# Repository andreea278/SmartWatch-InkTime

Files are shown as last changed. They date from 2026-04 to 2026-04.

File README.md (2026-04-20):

# SmartWatch InkTime 

Proiect de dezvoltare a unui ceas inteligent bazat pe microcontrolerul Nordic nRF52840, echipat cu un afișaj E-Ink și senzori pentru monitorizarea activității.

---

## Diagramă Bloc

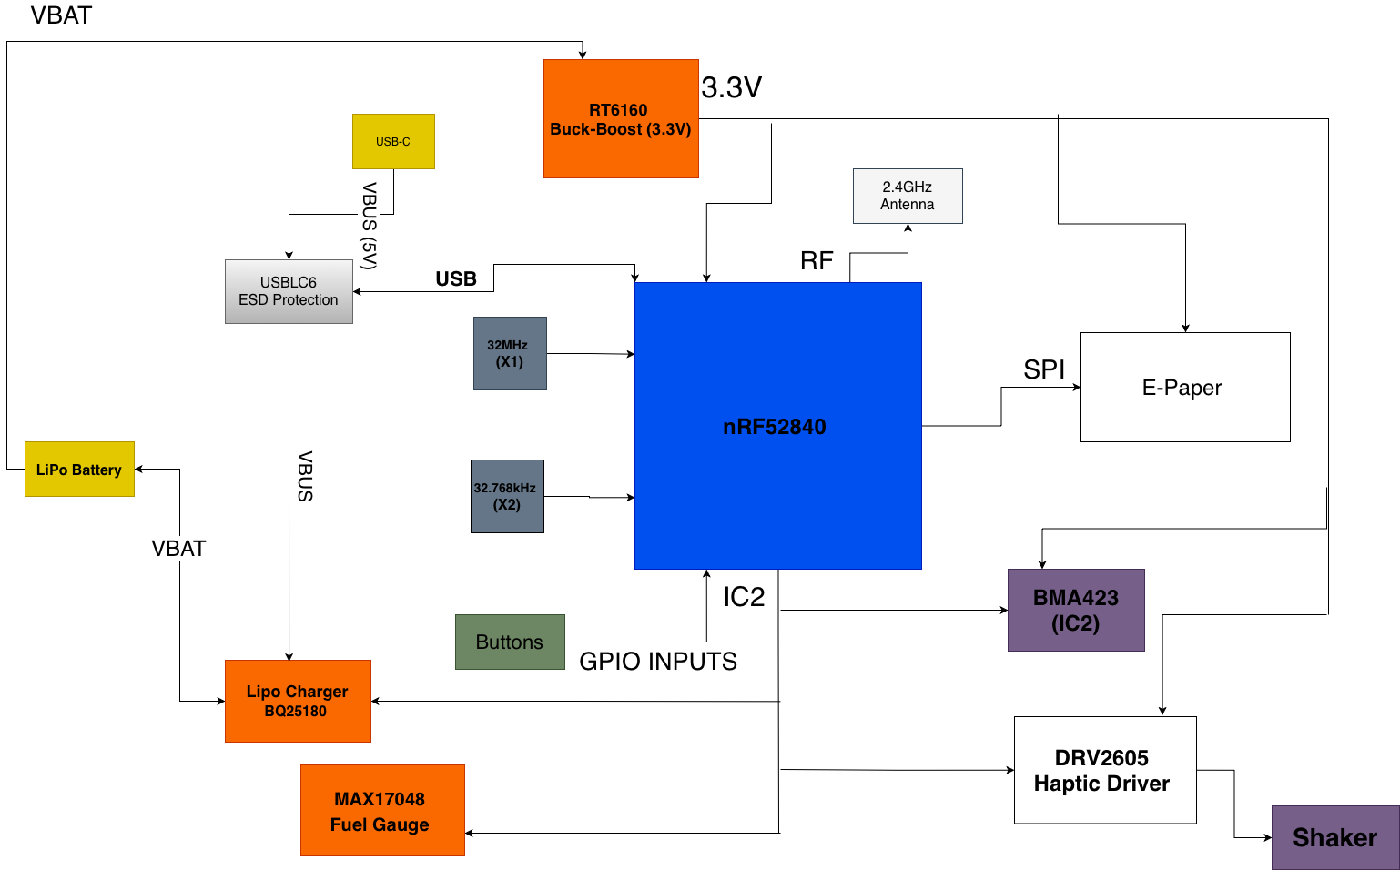
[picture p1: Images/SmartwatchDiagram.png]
Block Diagram


---
Acest proiect reprezintă o platformă open-hardware de tip smartwatch, proiectată pentru flexibilitate maximă și eficiență energetică ridicată. Construit în jurul microcontrolerului nRF52840 , dispozitivul oferă control total la nivel de regiștri pentru proiecte embedded avansate.

- **[nRF52840](https://www.nordicsemi.com/Products/nRF52840)(Microcontroler):** System on Chip bazat pe ARM Cortex-M4F tactat la 64 MHz. Include suport nativ pentru Bluetooth 5 / BLE și radio 2.4 GHz. Dispune de 1 MB Flash și 256 KB RAM și oferă interfețe versatile: SPI, I2C, UART și GPIO pentru comunicarea cu celelalte module.
- **[E-Paper 1.54"](https://www.waveshare.com/wiki/1.54inch_e-Paper_Module):** Ecran cu consum redus de energie, rezoluție 200x200 pixeli, comunică cu MCU-ul prin interfața SPI.
- **[BQ25180](https://www.ti.com/product/BQ25180)(Încărcător LiPo):** IC pentru încărcarea bateriei Li-Ion/Li-Po, controlat prin I2C. Gestionează alimentarea de 5V de la portul USB și oferă funcții de *power path management*.
- **[MAX17048](https://www.analog.com/en/products/max17048.html)(Fuel Gauge):** Cip pentru monitorizarea precisă a nivelului bateriei (State-of-Charge).
- **[RT6160](https://www.richtek.com/Products/Switching%20Regulators/Buck-Boost%20Converter/RT6160)(Regulator Buck-Boost):** Reglează tensiunea bateriei pentru a furniza o ieșire stabilă de 3.3V necesară componentelor sistemului.
- **Baterie LiPo (250 mAh):** Sursa principală de energie a dispozitivului.
- **[USBLC6-2](https://www.st.com/en/protections-and-safety/usblc6-2.html) (Protecție USB):** Protecție ESD (Electrostatic Discharge) pentru portul USB-C, prevenind deteriorarea componentelor interne.
- **[BMA423](https://www.bosch-sensortec.com/products/motion-sensors/accelerometers/bma423/):** Senzor MEMS pe 3 axe, ultra-low-power, optimizat pentru wearables, oferind funcții integrate precum numărarea pașilor, recunoașterea activității și detectarea mișcării prin întreruperi.
- **[DRV2605L](https://www.ti.com/product/DRV2605L) (Driver Haptic):** Driver controlat prin I2C pentru motorul de vibrații.
- [FIT0774](https://www.dfrobot.com/product-2264.html): Shaker
-  **[TC2030-IDC](https://www.tag-connect.com/product/tc2030-idc/)**: Conector programare SWD.
- **Cristale de tact:**
  - **[32 MHz (X1)](https://www.digikey.ro/en/products/detail/abracon-llc/ABM8G-32.000MHZ-18-D2Y-T/2269926):** Asigură frecvența principală de operare pentru MCU.
  - **[32.768 kHz (X2)](https://www.digikey.ro/en/products/detail/epson/FC-135-32.7680KA-A3/4522301):** Folosit pentru ceasul de timp real (RTC) și menținerea acurateței temporale.

## Bill of Materials (BOM)

Aceasta este lista principală de componente pentru proiectul smartwatch-ului bazat pe nRF52840.

| Component | Descriere | Cantitate | Producător | Cod Piesă | Datasheet |
| :--- | :--- | :---: | :--- | :--- | :---: |
| **nRF52840** | BLE Microcontroller | 1 | Nordic Semiconductor | nRF52840 | [Link](https://files.seeedstudio.com/wiki/XIAO-BLE/Nano_BLE_MCU-nRF52840_PS_v1.1.pdf) |
| **BMA423** | Accelerometru 3-axe (IMU) | 1 | Bosch | BMA423 | [Link](https://watchy.sqfmi.com/assets/files/BST-BMA423-DS000-1509600-950150f51058597a6234dd3eaafbb1f0.pdf) |
| **BQ25180** | Încărcător baterie / PMIC | 1 | Texas Instruments | BQ25180 | [Link](https://www.ti.com/product/BQ25180) |
| **DRV2605L** | Driver haptic | 1 | Texas Instruments | DRV2605L | [Link](https://www.ti.com/product/BQ25180) |
| **MAX17048** | Fuel gauge | 1 | Analog Devices | MAX17048G+T10 | [Link](https://www.analog.com/en/products/max17048.html) |
| **RT6160** | Buck-boost converter | 1 | Richtek | RT6160AWSC | [Link](https://www.mouser.com/datasheet/2/1458/DS6160A_02-3104604.pdf) |
| **2450AT18B100E** | Antenă chip 2.4GHz | 1 | Johanson Technology | 2450AT18B100E | [Link](https://jlcpcb.com/api/file/downloadByFileSystemAccessId/8588940948130156544) |
| **TC2030-IDC** | Conector programare | 1 | Tag-Connect | TC2030-IDC | [Link](https://www.lcsc.com/datasheet/C5444772.pdf) |
| **USB-C Connector** | Interfață alimentare/date | 1 | Kinghelm | KH-TYPE-C-16P | [Link](https://jlcpcb.com/api/file/downloadByFileSystemAccessId/8588905154556923904) |
| **FPC Connector** | Conector display e-paper | 1 | Molex | 503480-2400 | [Link](https://www.molex.com/content/dam/molex/molexdotcom/products/automated/enus/salesdrawingpdf/503/503480/5034802400_sd.pdf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) |
| **Push Buttons** | Switch-uri tactile | 3 | Panasonic | EVP-AKE31A | [Link](https://wmsc.lcsc.com/wmsc/upload/file/pdf/v2/lcsc/2301111010_PANASONIC-EVPAKE31A_C569760.pdf) |
| **MOSFETs** | Comutare putere | 2 | Vishay / Diodes Inc. | SI1308EDL / DMG2305UX | [Link](https://www.lcsc.com/datasheet/C469327.pdf) |
| **Diodes** | Diode Schottky | 3 | ON Semiconductor | MBR0530 | [Link](https://www.lcsc.com/datasheet/C77336.pdf) |
| **ESD Protection** | Protecție USB | 1 | STMicroelectronics | USBLC6-2SC6 | [Link](https://www.lcsc.com/datasheet/C7519.pdf) |
| **Crystal** | 32MHz | 1 | NDK | NX2016SA-32MHZ-EXS00A-CS11336 | [Link](https://wmsc.lcsc.com/wmsc/upload/file/pdf/v2/lcsc/2312080231_NDK-NX2016SA-32MHZ-EXS00A-CS11336_C6134317.pdf) |
| **Crystals** | 32.768kHz | 1 | Seiko Epson | FC-135 32.7680KA-A3 | [Link](https://jlcpcb.com/partdetail/SeikoEpson-FC_135_32_7680KAA3/C2650472) |

---

##  Arhitectură și Specificații Hardware

### 1. Unitatea de Procesare (CPU)
* **Microcontroler:** **nRF52840 (Nordic Semiconductor)**
    * **Arhitectură:** ARM Cortex-M4F (cu FPU), tactat la 64 MHz.
    * **Capabilități:** Suport nativ Bluetooth 5.4 (BLE), radio 2.4 GHz.
    * **Memorie:** 1 MB Flash, 256 KB RAM.
    * **Rol:** Procesare centrală, gestionarea stivei Bluetooth și coordonarea perifericelor.

### 2. Sistemul de Management al Energiei (PMU)
Sistemul utilizează un lanț de alimentare eficient pentru a prelungi durata de viață a bateriei:

* **Încărcare (PMIC):** **BQ25180**
    * Gestionează alimentarea de 5V (USB-C) și oferă protecție integrată.
* **Reglare Tensiune:** **RT6160 (Buck-Boost)**
    * Converteste tensiunea bateriei (3.0V - 4.2V) la o linie stabilă de **3.3V** cu o eficiență de peste 90%.
* **Monitorizare:** **MAX17048 (Fuel Gauge)**
    * Algoritm *ModelGauge* pentru estimarea precisă a nivelului bateriei.
 
 ### 3. Matricea de Comunicare
Sistemul utilizează magistrale digitale pentru a minimiza numărul de pini ocupați:

| Protocol | Componente Conectate | Funcție |
| :--- | :--- | :--- |
| **SPI** | E-Paper Display | Transfer rapid de pixeli pentru refresh. |
| **I2C** | BMA423, BQ25180, DRV2605L, MAX17048 | Magistrală partajată pentru senzori și PMU. |
| **GPIO** | Butoane fizice, Interrupts (BMA423) | Input utilizator și wake-up trigger. |
| **SWD** | Conector TC2030-IDC | Interfață de programare și debugging. |

### 4. Periferice 
* **Afișaj:** E-Paper 1.54" (200x200).
    * *Avantaj:* Consum de energie zero pentru menținerea imaginii (bistabil).
* **Senzor:** **BMA423 (Accelerometru)**.
    * *Rol:* Detecția pașilor, recunoașterea activității și trezirea MCU-ului din `Deep Sleep`.
* **Feedback Haptic:** **DRV2605L** + Motor vibrații.
    * *Rol:* Driver haptic inteligent pentru feedback tactil avansat (click-uri, alerte), controlat via I2C.

---

## 4. Mapare Pini nRF52840

| Pin nRF52840 | Semnal | Componentă | Interfață |
| :--- | :--- | :--- | :--- |
| **P0.00** | XL1 | Cristal X2 (32.768kHz) | XTAL |
| **P0.01** | XL2 | Cristal X2 (32.768kHz) | XTAL |
| **P0.02** | SCK | E-Paper (J1 FPC) | SPI SCK |
| **P0.03** | MOSI | E-Paper (J1 FPC) | SPI MOSI |
| **P0.05** | EPD_CS | E-Paper (J1 FPC) | SPI CS |
| **P0.06** | SDA | BMA423, BQ25180, MAX17048, DRV2605 | I2C SDA |
| **P0.07** | SCL | BMA423, BQ25180, MAX17048, DRV2605 | I2C SCL |
| **P0.08** | IMU_INT1 | BMA423 | GPIO Input |
| **P1.08** | IMU_INT2 | BMA423 | GPIO Input |
| **P0.10** | ALERT | MAX17048 | GPIO Input |
| **P0.11** | PMIC_INT | BQ25180 | GPIO Input |
| **P0.12** | HAPTIC_EN | DRV2605 | GPIO Output |
| **P0.13** | SW_UP | Buton Up | GPIO Input |
| **P0.14** | SW_ENT | Buton Enter | GPIO Input |
| **P0.15** | EPD_DC | E-Paper (J1 FPC) | GPIO |
| **P0.16** | EPD_RST | E-Paper (J1 FPC) | GPIO |
| **P0.17** | EPD_BUSY | E-Paper (J1 FPC) | GPIO Input |
| **P0.18** | RESET | TC2030-IDC | SWD / Reset |
| **P1.02** | SW_DN | Buton Down | GPIO Input |
| **SWDCLK** | SWDCLK | TC2030-IDC | SWD |
| **SWDIO** | SWDIO | TC2030-IDC | SWD |
| **ANT** | RF | Antenă 2450AT18B100E | RF |

---
## 5. Specificații Design PCB

### Reguli de Proiectare 
* **Strat 1 (Top):** Componente și rutare semnal.
* **Strat 2 (Internal):** Plan Putere (VCC/3V3).
* **Strat 3 (Internal):** Plan Masă (GND).
* **Strat 4 (Bottom):** Rutare semnal și componente.

### Constrângeri DRC
* **Trasee Putere:** 0.3 mm (îngustate sub BGA).
* **Trasee Date:** 0.15 mm (min).
* **Unghiuri:** Doar 45° sau rotunjite.
* **Antenă:** Zonă "Keep-out" (fără cupru) pe toate straturile sub antenă.
* **Decuplare:** Condensatoarele de 100nF plasate direct pe pinii de alimentare.

### Erori DRC Acceptate
* **Copper Clearance (Aprobat):** În zona fan-out-ului pentru nRF52840, clearance-ul a fost redus manual sub 0.15mm pentru a permite rutarea corectă a pinilor AQFN cu pitch mic.

---

### Design PCB
| **Top Layer** | **Bottom Layer** | **Silkscreen** |
| :---: | :---: | :---: |
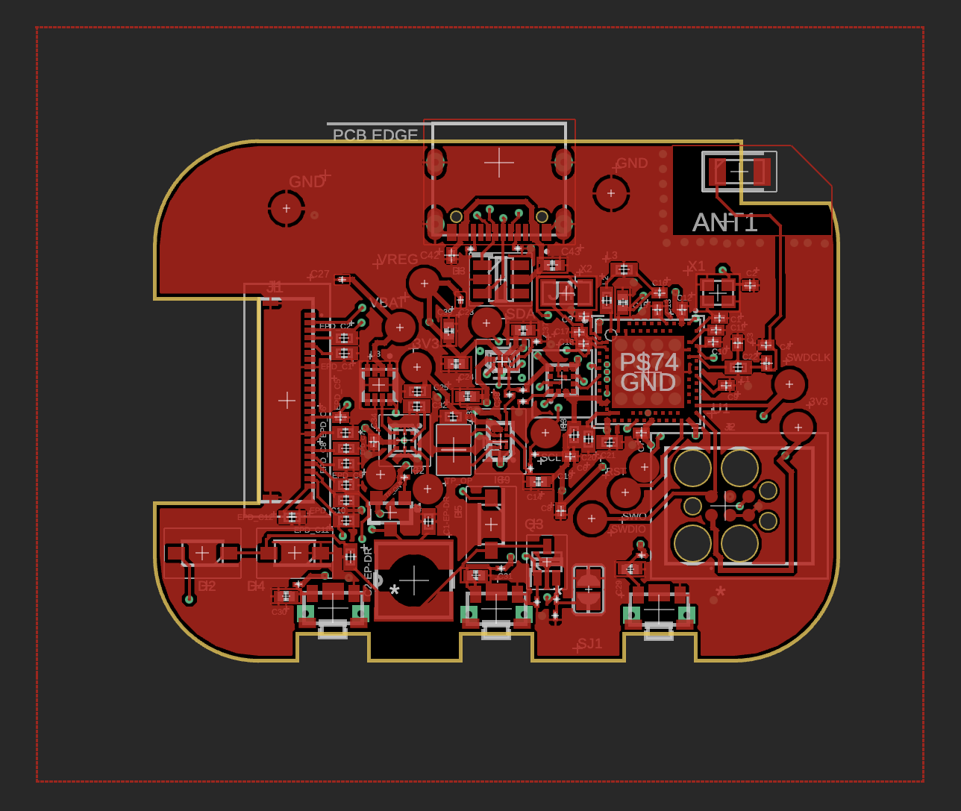
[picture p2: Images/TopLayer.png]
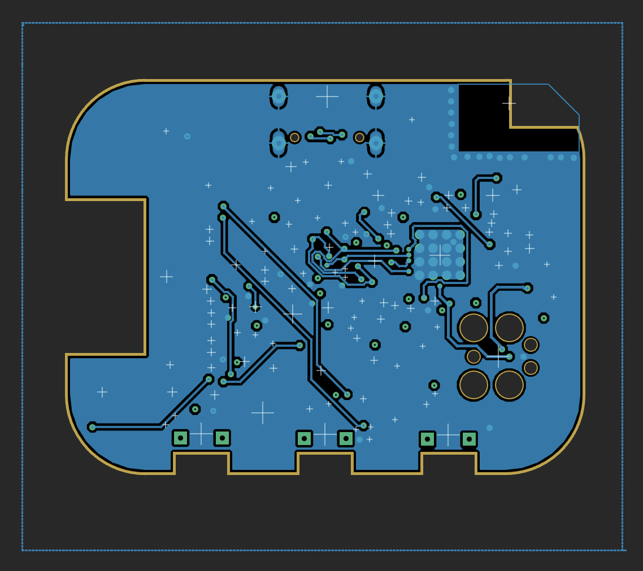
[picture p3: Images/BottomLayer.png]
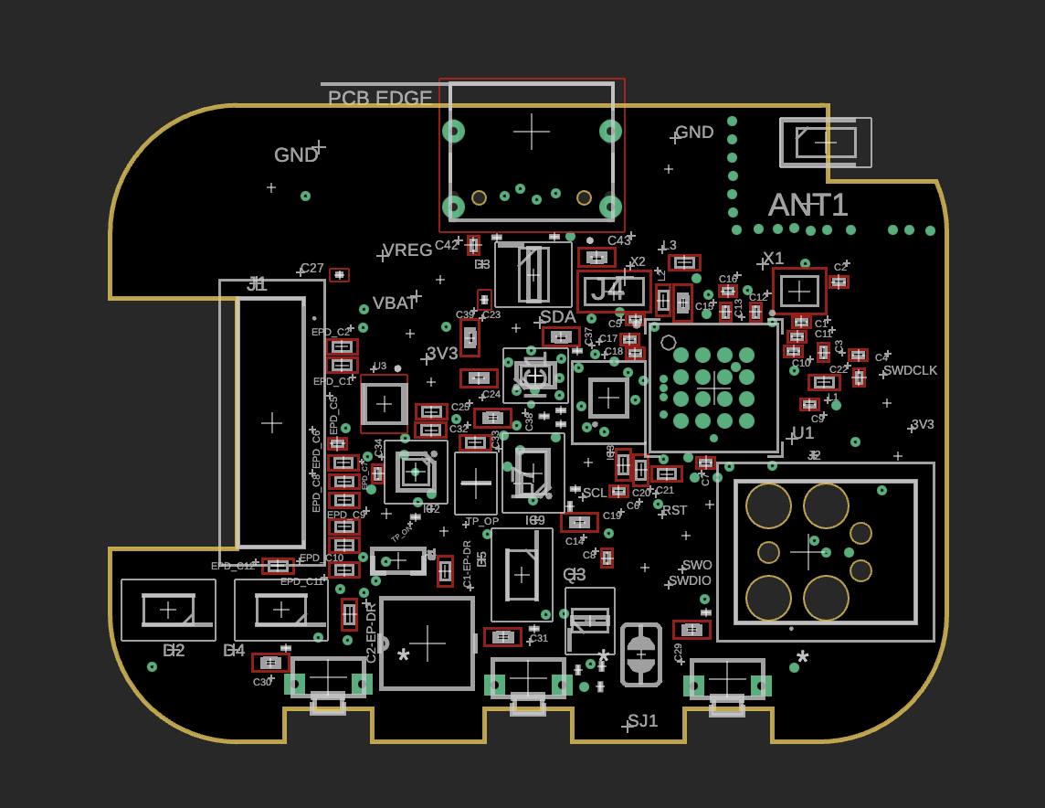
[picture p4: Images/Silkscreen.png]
|  |  |  |
| **Inner Layer 2 (GND)** | **Inner Layer 3 (Power - C63)** |
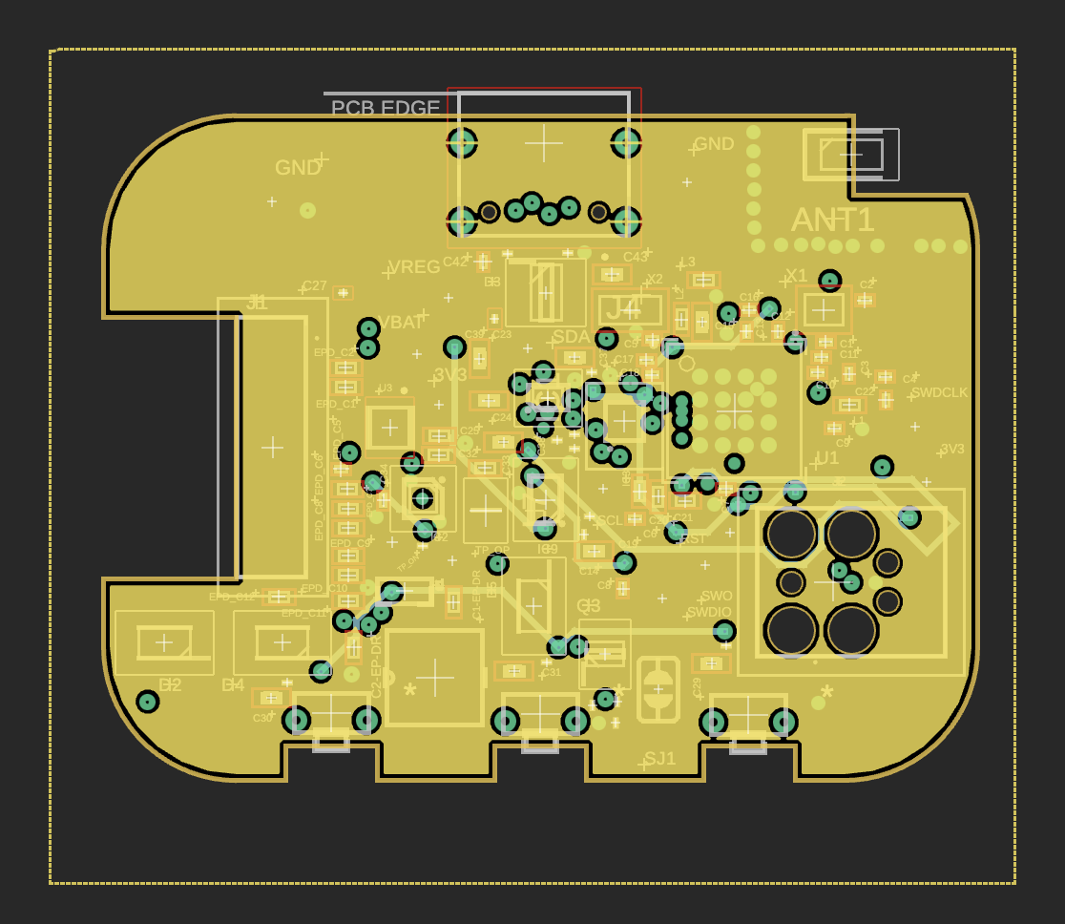
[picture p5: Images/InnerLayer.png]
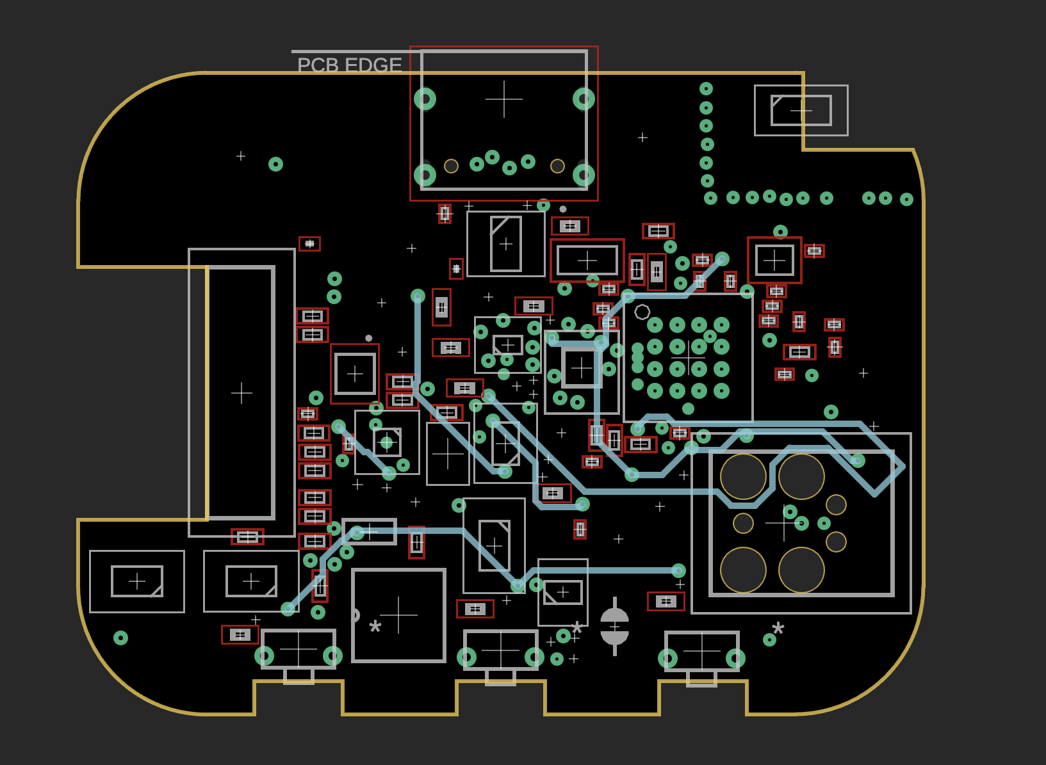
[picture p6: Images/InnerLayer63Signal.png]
|  |  |

### Design Schematic
---

| Pagina 1 - MCU & Power | Pagina 2 - Display & Senzori |
|:---:|:---:|
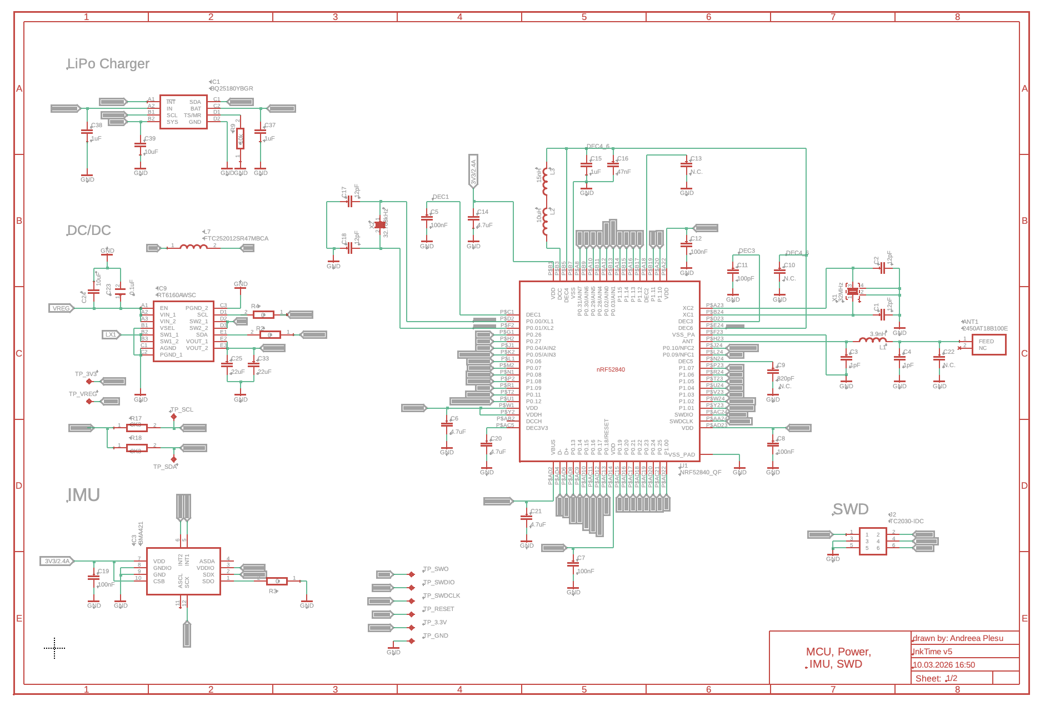
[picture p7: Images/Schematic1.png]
Schematic 1
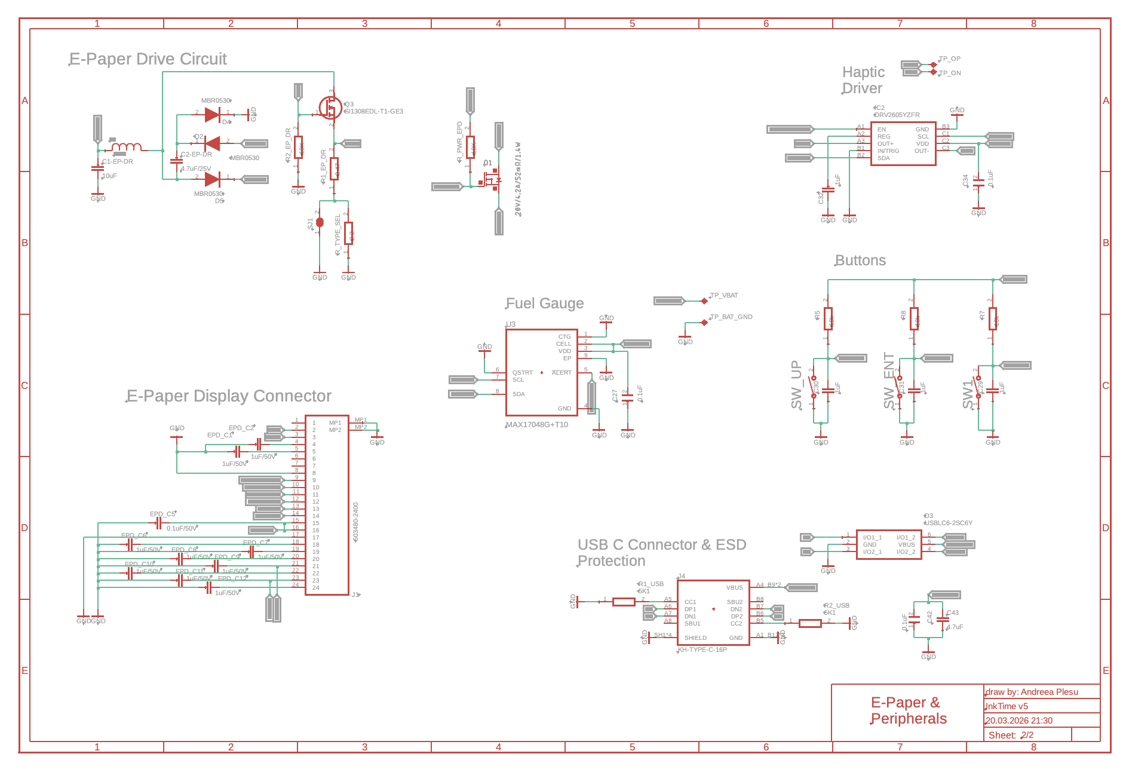
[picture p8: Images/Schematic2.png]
Schematic 2
|  width="300" |  width="300" |

---

### 3D PCB & Carcasa
| **Top View** | 
| :---: | 
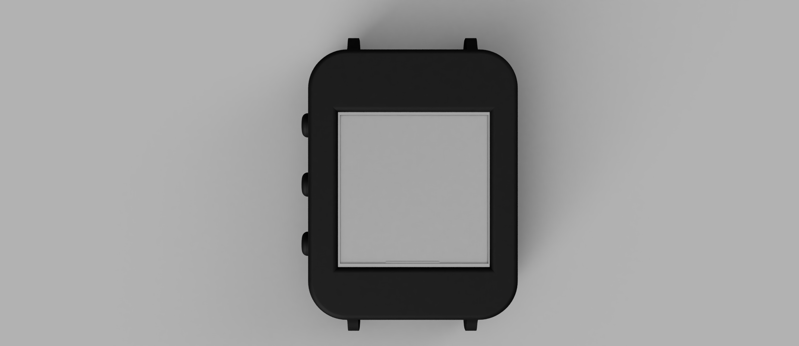
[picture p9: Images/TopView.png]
|  | 
**Side View** |
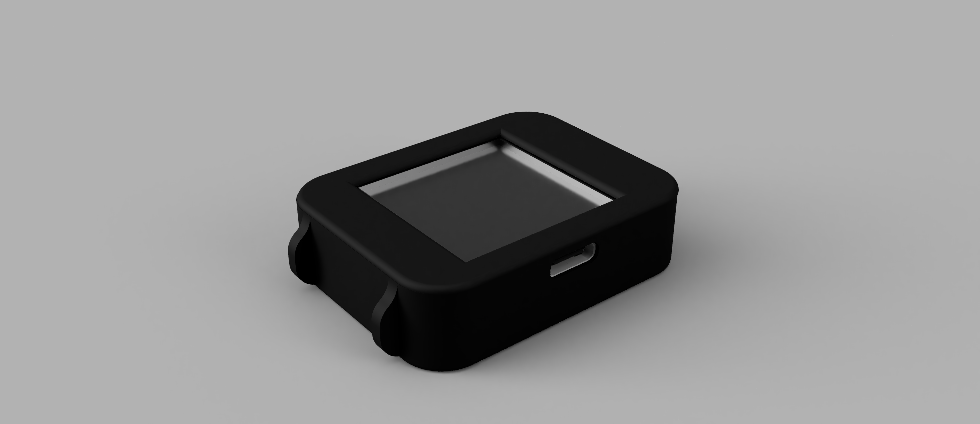
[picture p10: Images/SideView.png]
|  |
|  **SmartWatch Components** |
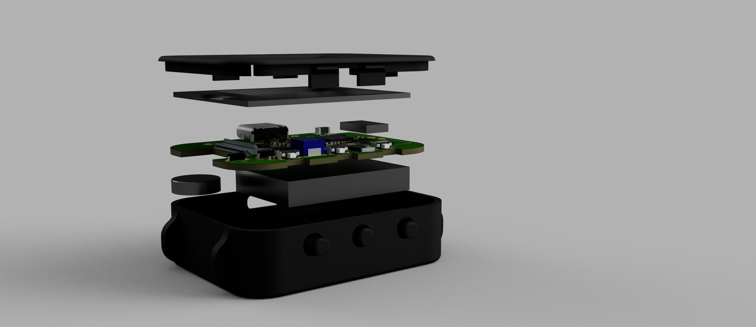
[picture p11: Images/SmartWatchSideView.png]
|  |

---

## 6. Structură 
* `Hardware/` - Fișierele sursă `.sch` și `.brd` .
* `Manufacturing/` - Fișiere Gerber, BOM și Pick & Place.
* `Mechanical/` - Modelul 3D al dispozitivului în format `.f3d` și `.step` (exploded view).
* `Images/` - Randări și screenshot-uri ale proiectului.

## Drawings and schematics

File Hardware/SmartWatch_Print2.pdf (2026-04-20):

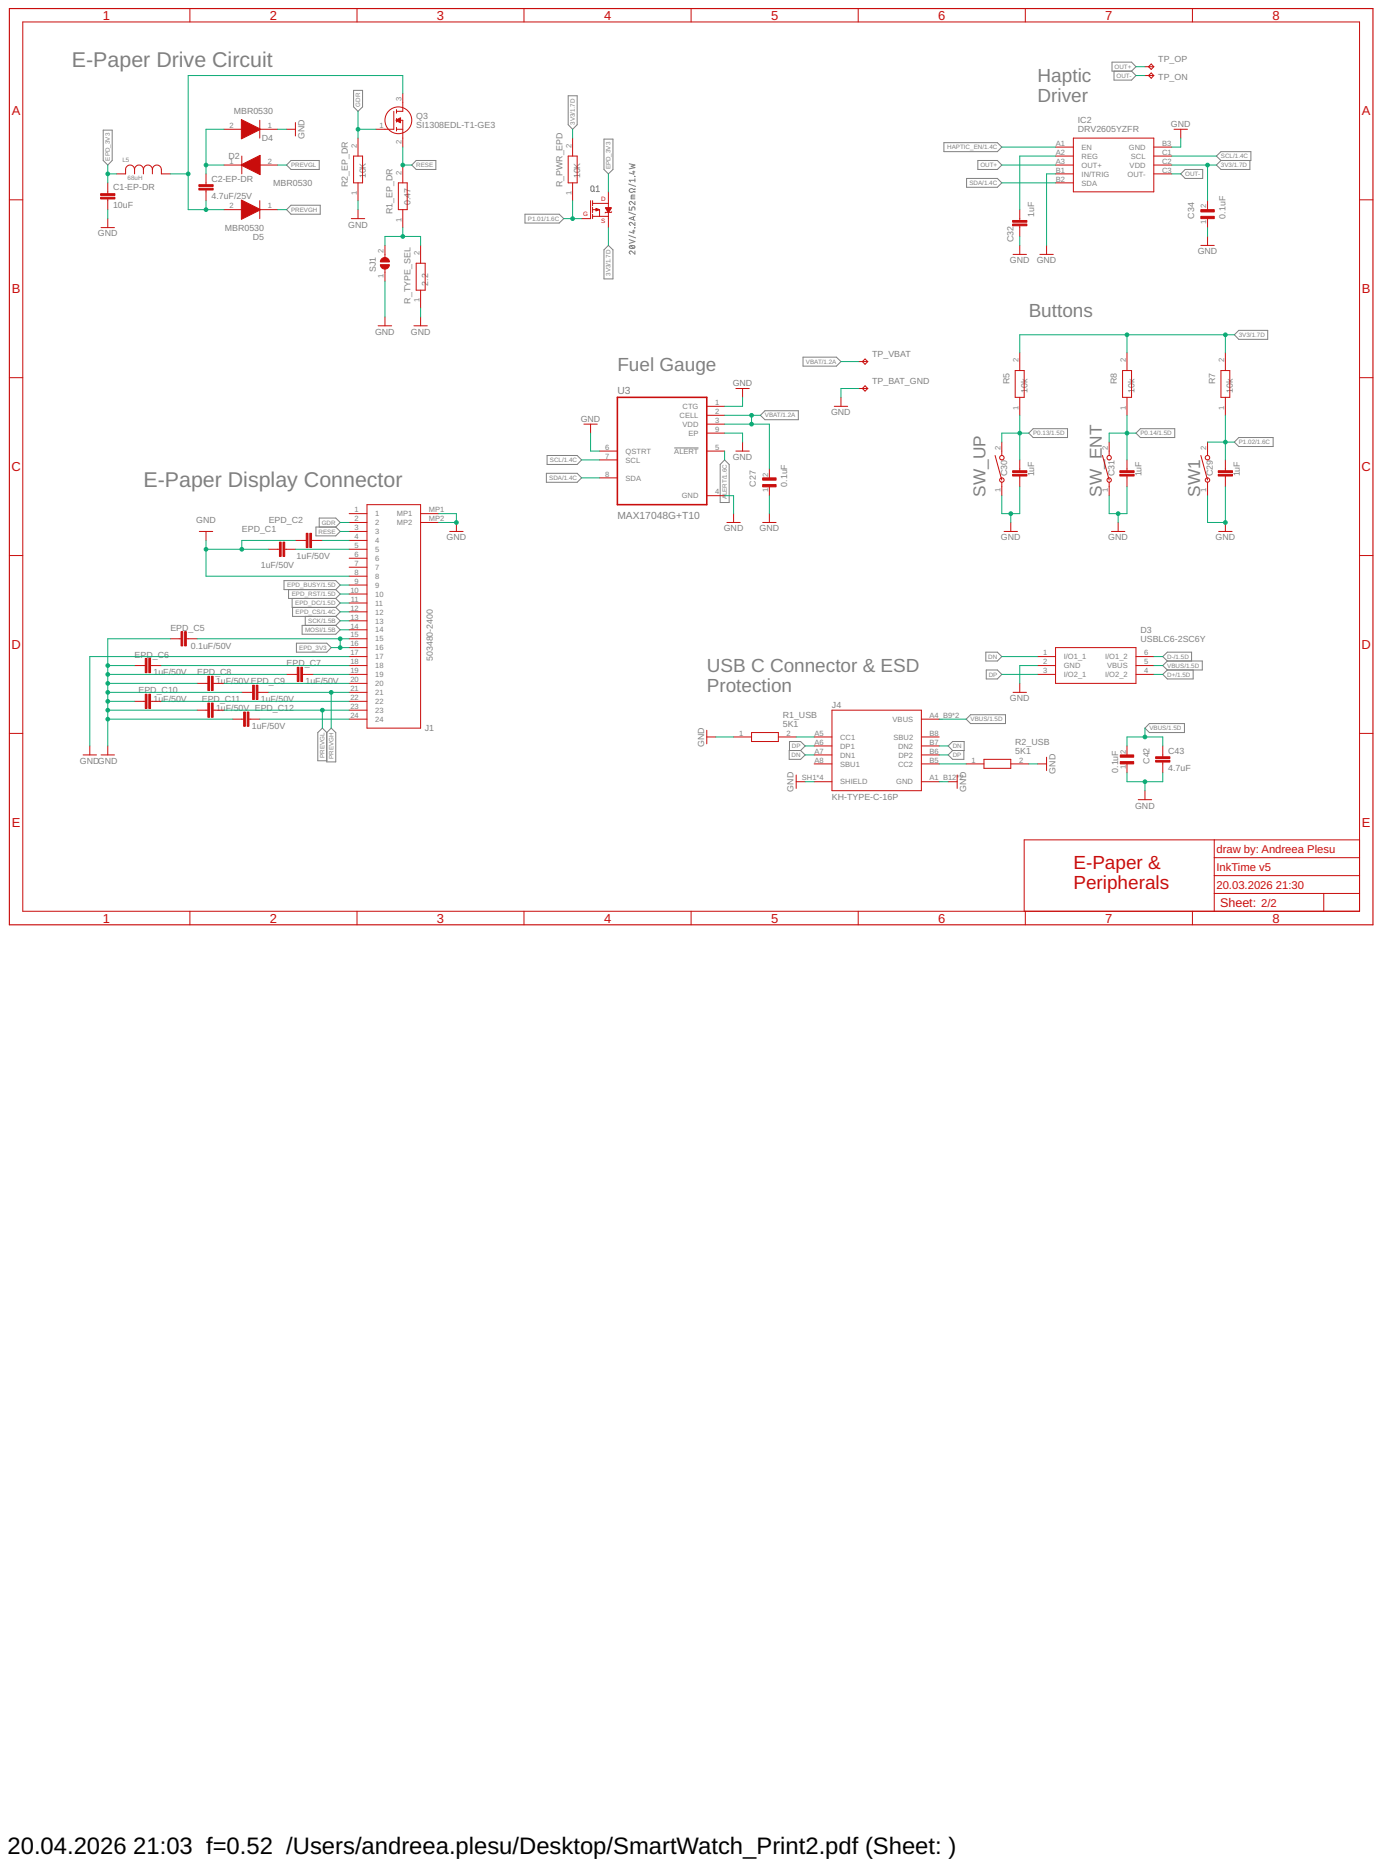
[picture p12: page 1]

20.04.2026 21:03 f=0.52 /Users/andreea.plesu/Desktop/SmartWatch_Print2.pdf (Sheet: )

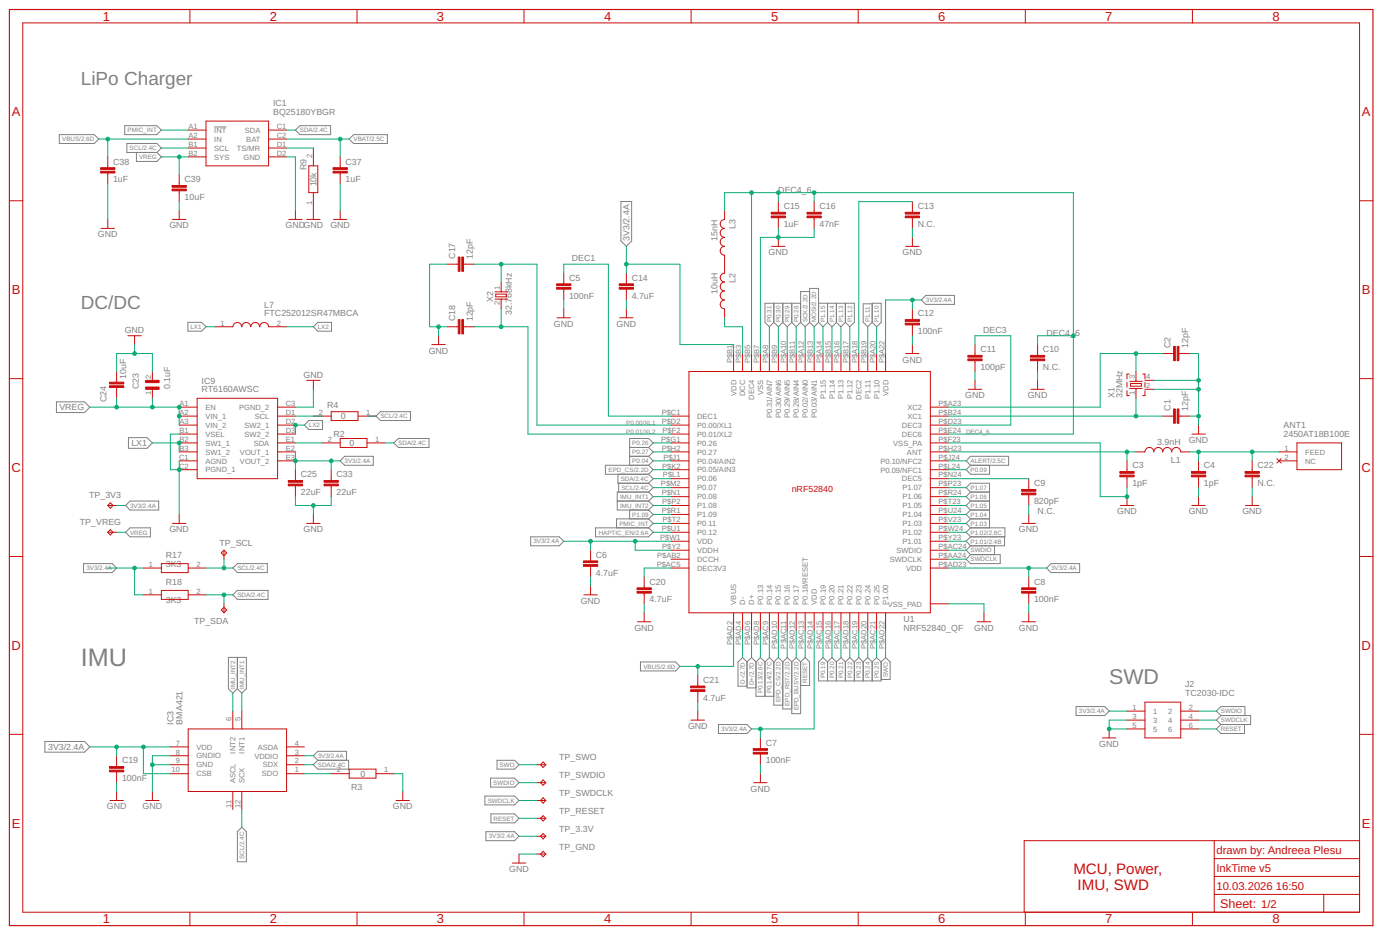
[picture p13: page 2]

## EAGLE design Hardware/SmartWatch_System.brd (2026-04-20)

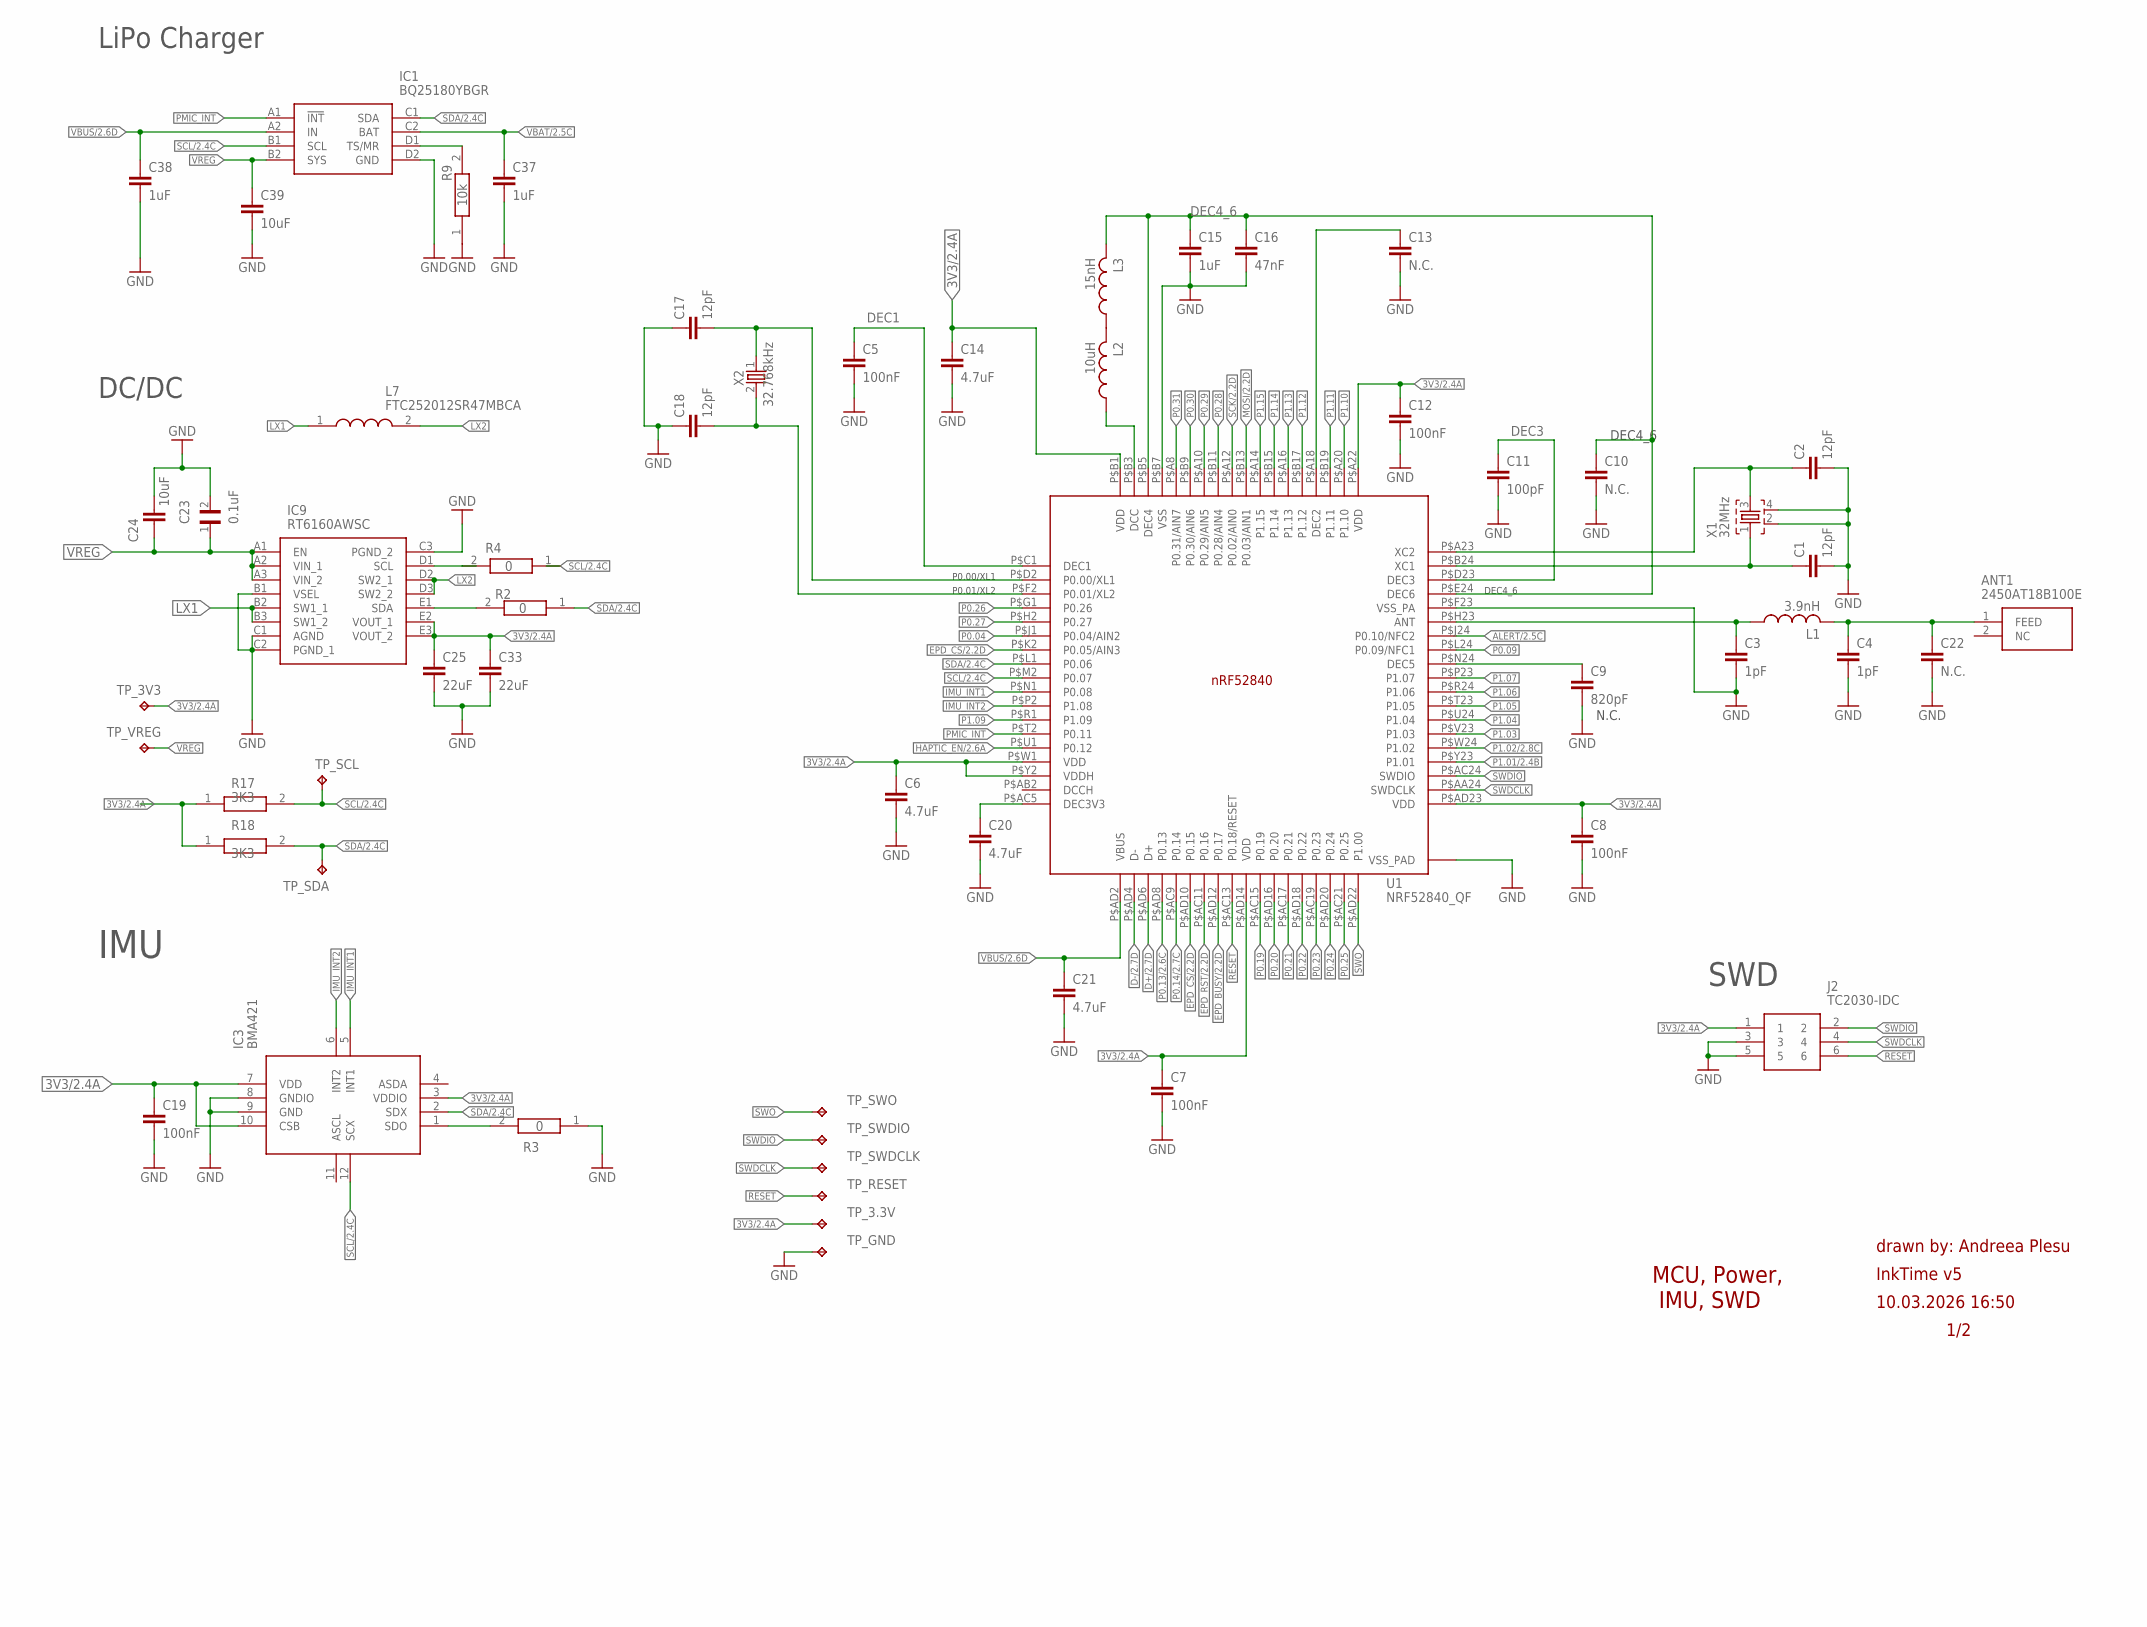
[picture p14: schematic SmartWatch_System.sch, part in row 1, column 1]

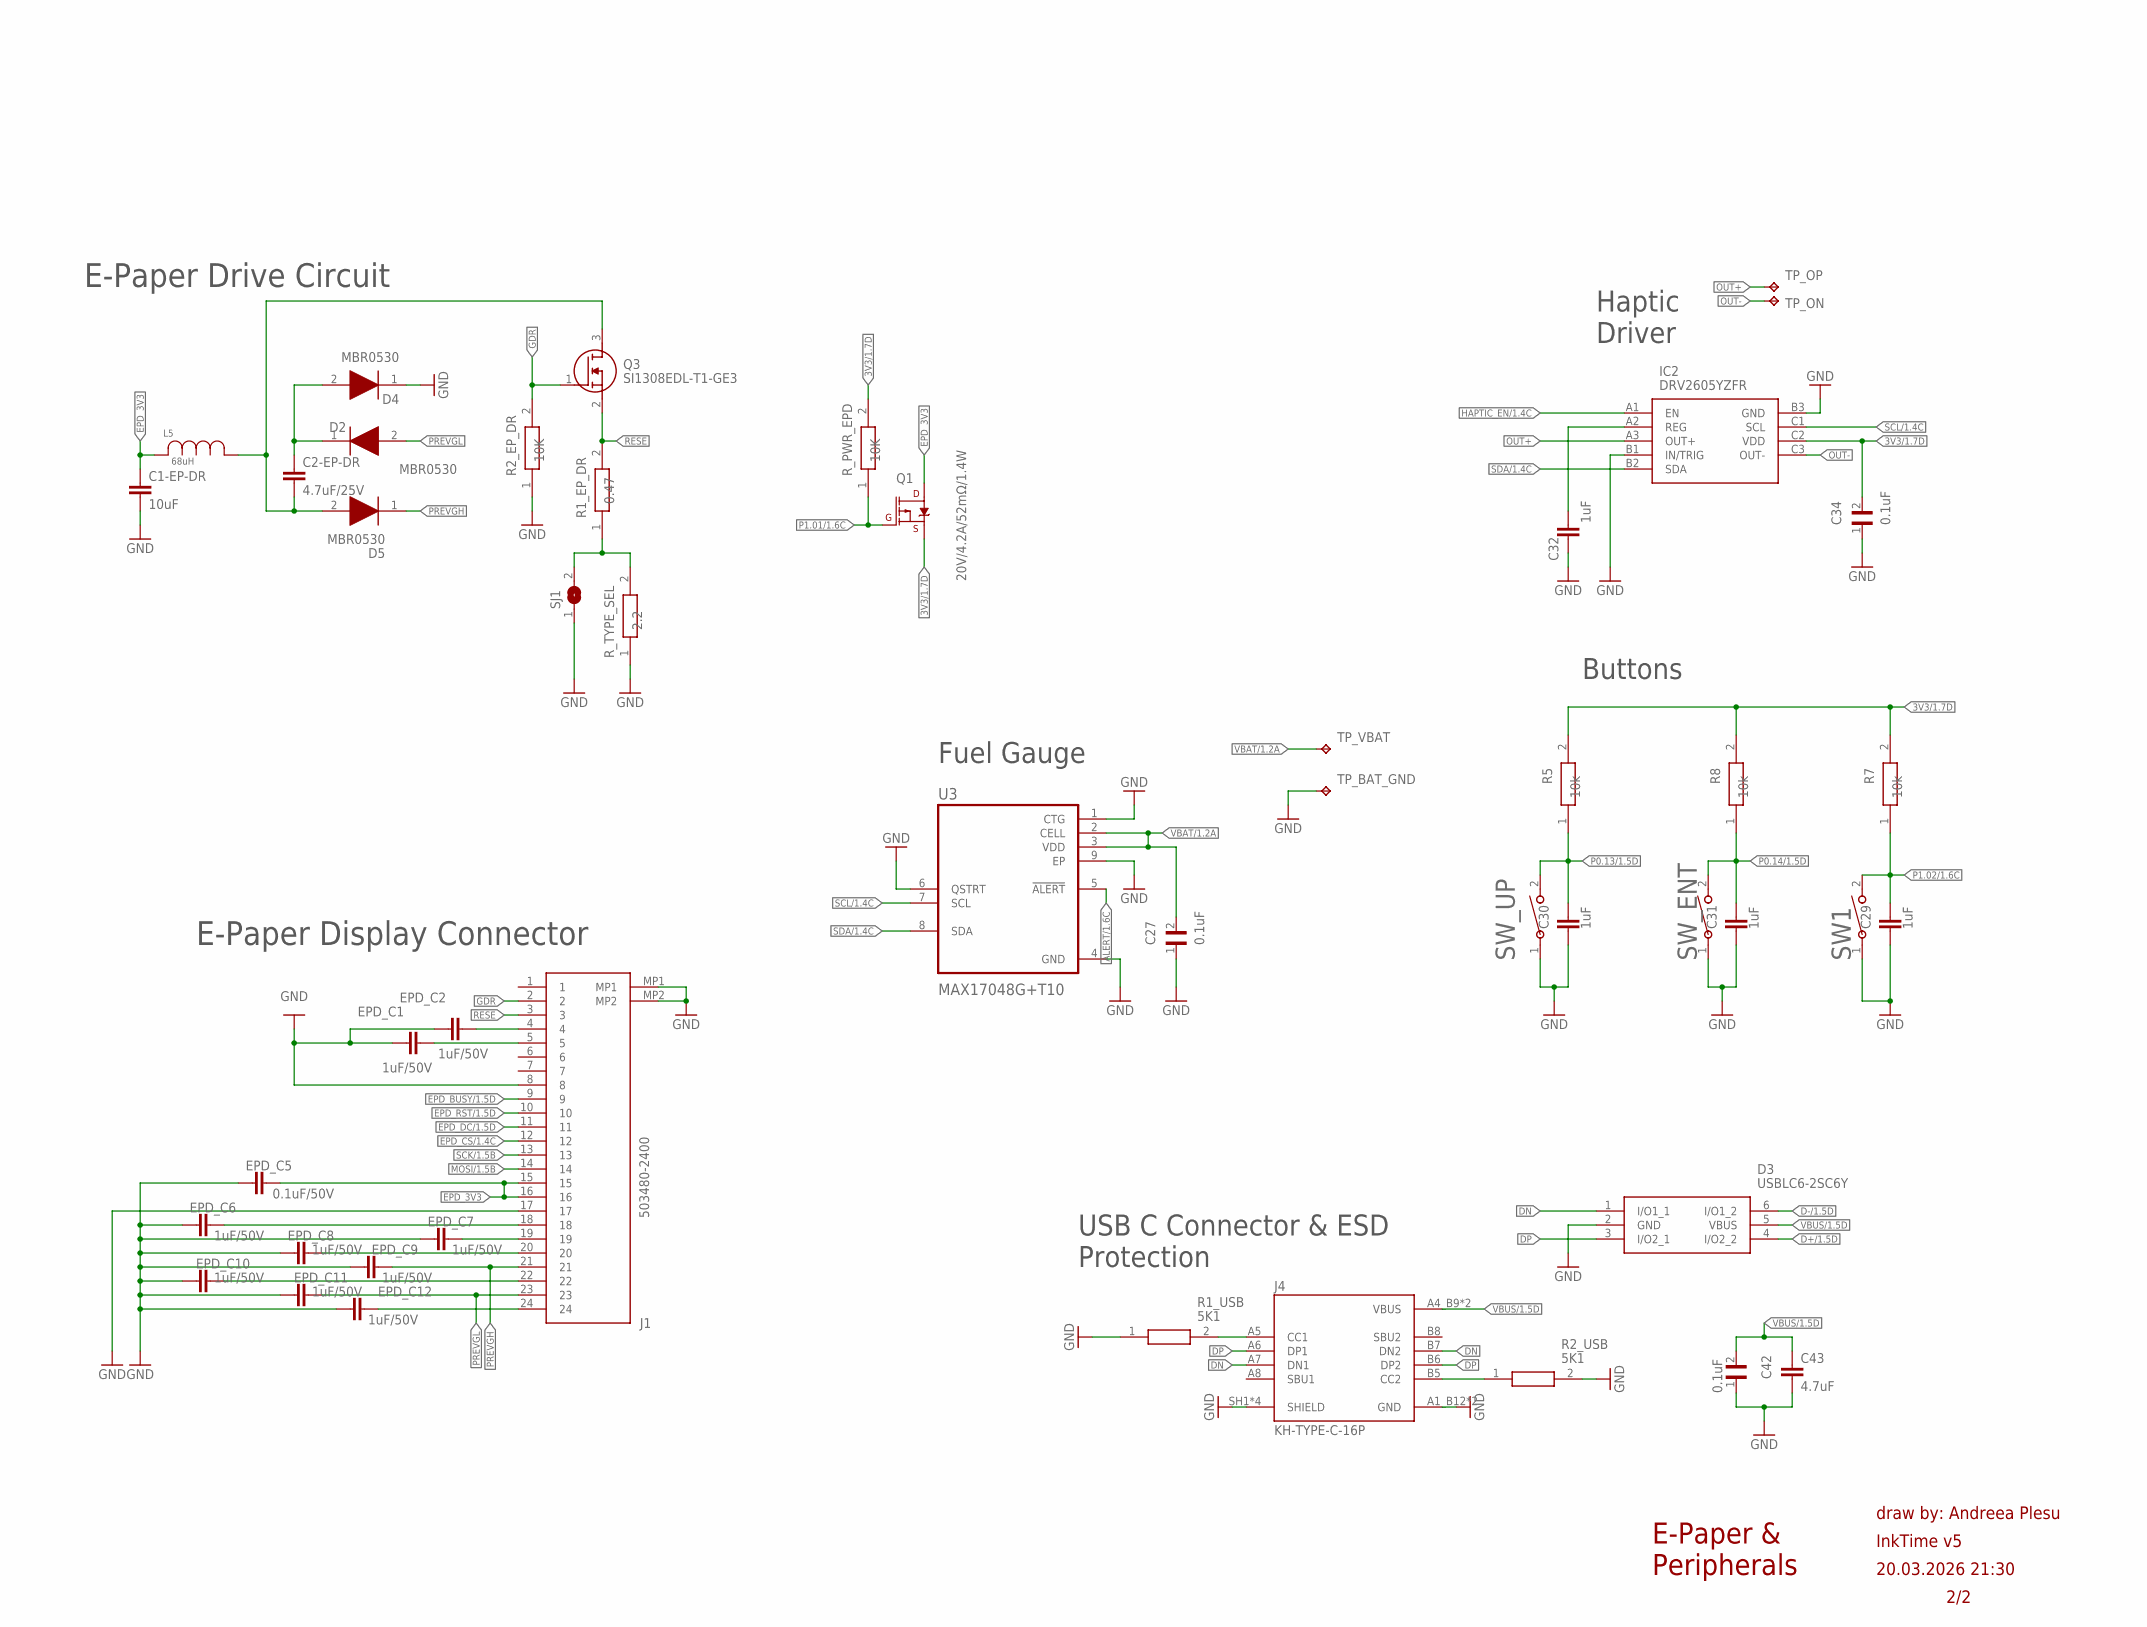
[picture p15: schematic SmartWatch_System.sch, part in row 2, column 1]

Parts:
ANT1: 2450AT18B100E; 2450AT18B100E_ANTC3216X140N
C1, C2, C17, C18: 12pF; NORDIC_NRF_3_RESC0201_L
C1-EP-DR: 10uF; NORDIC_NRF_3_RESC0402_L
C2-EP-DR: 4.7uF/25V; NORDIC_NRF_3_RESC0402_L
C3, C4: 1pF; NORDIC_NRF_3_RESC0201_L
C5, C7, C8, C12, C19: 100nF; NORDIC_NRF_3_RESC0201_L
C6, C20, C21: 4.7uF; NORDIC_NRF_3_RESC0402_L
C9: 820pF; NORDIC_NRF_3_RESC0201_L
C10, C13, C22: N.C.; NORDIC_NRF_3_RESC0201_L
C11: 100pF; NORDIC_NRF_3_RESC0201_L
C14, C43: 4.7uF; PERFECT_0402_0402
C15, C29, C30, C31, C37, C38: 1uF; PERFECT_0402_0402
C16: 47nF; NORDIC_NRF_3_RESC0201_L
C23, C27: 0.1uF; GRM011R60J152KE01L_2_CAPC0201X13N
C24, C39: 10uF; PERFECT_0402_0402
C25, C33: 22uF; NORDIC_NRF_3_RESC0402_L
C32: 1uF; NORDIC_NRF_3_RESC0402_L
C34, C42: 0.1uF; NORDIC_NRF_3_RESC0201_L
D2, D4, D5: MBR0530; ESP32_C6_LIBRARY_5_SOD3716X135N
D3: USBLC6-2SC6Y; ESP32_C6_LIBRARY_3_SOT95P280X145-6N
EPD_C1, EPD_C2, EPD_C6, EPD_C7, EPD_C8, EPD_C9, EPD_C10, EPD_C11, EPD_C12: 1uF/50V; NORDIC_NRF_3_RESC0402_L
EPD_C5: 0.1uF/50V; NORDIC_NRF_3_RESC0201_L
IC1: BQ25180YBGR; BQ25180YBGR_BGA8C40P2X4_100X155X50
IC2: DRV2605YZFR; DRV2605YZFR_BGA9C50P3X3_144X144X62
IC3: BMA421; BMA423_BMA423
IC9: RT6160AWSC; RT6160AWSC_BGA15C40P3X5_140X230X60
J1: 503480-2400; 503480-2400_5034802400
J2: TC2030-IDC; TC2030-IDC_TC2030IDC
J4: KH-TYPE-C-16P; KH-TYPE-C-16P_KINGHELM_KH-TYPE-C-16P
L1: 3.9nH; NORDIC_NRF_2_RESC0402_L
L2: 10uH; NORDIC_NRF_2_RESC0402_L
L3: 15nH; NORDIC_NRF_2_RESC0402_L
L5: 68uH; ESP32_C6_LIBRARY_2_IND_4828-WE-TPC_WRE
L7: FTC252012SR47MBCA; MLP2016SR47MT0S1_INDC2016X100N
Q1: 20V/4.2A/52mΩ/1.4W; ESP32_C6_LIBRARY_4_ESP32_C6_LIBRARY_4_ESP32_C6_LIBRARY_4_ES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
Q3: SI1308EDL-T1-GE3; ESP32_C6_LIBRARY_6_SOT65P210X110-3N
R1_EP_DR: 0.47; CPF0201D7K68C1_0201
R1_USB, R2_USB: 5K1; CPF0201D7K68C1_0201
R2, R4: 0; ERA-1AEB3401C_0201
R2_EP_DR: 10K; CPF0201D7K68C1_0201
R3: 0; CPF0201D7K68C1_0201
R5, R7, R8: 10k; CPF0201D7K68C1_0201
R9: 10k; ERA-1AEB3401C_0201
R17, R18: 3K3; ERA-1AEB3401C_0201
R_PWR_EPD: 10K; CPF0201D7K68C1_0201
R_TYPE_SEL: 2.2; CPF0201D7K68C1_0201
SJ1: ESP32_C6_LIBRARY_7_JUMPER_SJ
SW1: 2025-10-22_07-23-44_LIBRARY_EVP-AKE31ASW_EVP-AKE3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; 2025-10-22_07-23-44_LIBRARY_SW_EVP-AKE31A_PAN
SW_ENT: 2025-10-22_07-23-44_LIBRARY_EVP-AKE31ASW_EVP-AKE3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; 2025-10-22_07-23-44_LIBRARY_SW_EVP-AKE31A_PAN
SW_UP: 2025-10-22_07-23-44_LIBRARY_EVP-AKE31ASW_EVP-AKE3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; 2025-10-22_07-23-44_LIBRARY_SW_EVP-AKE31A_PAN
TP_3.3V, TP_3V3: HECTOR_WATCH_1_TPTP20R; HECTOR_WATCH_1_TP20R
TP_BAT_GND: HECTOR_WATCH_1_TPTP20R; HECTOR_WATCH_1_TP20R
TP_GND: HECTOR_WATCH_1_TPTP20R; HECTOR_WATCH_1_TP20R
TP_ON: HECTOR_WATCH_1_TPTP20R; HECTOR_WATCH_1_TP20R
TP_OP: HECTOR_WATCH_1_TPTP20R; HECTOR_WATCH_1_TP20R
TP_RESET: HECTOR_WATCH_1_TPTP20R; HECTOR_WATCH_1_TP20R
TP_SCL: HECTOR_WATCH_1_TPTP20R; HECTOR_WATCH_1_TP20R
TP_SDA: HECTOR_WATCH_1_TPTP20R; HECTOR_WATCH_1_TP20R
TP_SWDCLK: HECTOR_WATCH_1_TPTP20R; HECTOR_WATCH_1_TP20R
TP_SWDIO: HECTOR_WATCH_1_TPTP20R; HECTOR_WATCH_1_TP20R
TP_SWO: HECTOR_WATCH_1_TPTP20R; HECTOR_WATCH_1_TP20R
TP_VBAT: HECTOR_WATCH_1_TPTP20R; HECTOR_WATCH_1_TP20R
TP_VREG: HECTOR_WATCH_1_TPTP20R; HECTOR_WATCH_1_TP20R
U1: NRF52840_QF; NORDIC_NRF_4_AQFN50P700X700X85_HS-74N
U3: MAX17048G+T10; ESP32_C6_LIBRARY_SON50P200X200X80-9N
X1: 32MHz; NORDIC_NRF_BT-XTAL_2016_N
X2: 32.768kHz; NORDIC_NRF_1_XTAL_3215_N

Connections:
3V3/1.7D: C34.2, IC2.C2 (VDD), Q1.2 (S), R5.2, R7.2, R8.2, R_PWR_EPD.2
3V3/2.4A: C6.1, C7.1, C8.1, C12.1, C14.1, C19.1, C25.1, C33.1, IC3.3 (VDDIO), IC3.7 (VDD), IC3.10 (CSB), IC9.E2 (VOUT_1), IC9.E3 (VOUT_2), J2.1, R17.1, R18.1, TP_3.3V.TP, TP_3V3.TP, U1.P$A22 (VDD), U1.P$AD14 (VDD), U1.P$AD23 (VDD), U1.P$B1 (VDD), U1.P$W1 (VDD), U1.P$Y2 (VDDH)
ALERT/1.6C: U3.5 (!ALERT)
ALERT/2.5C: U1.P$J24 (P0.10/NFC2)
D+/1.5D: D3.4 (I/O2_2)
D+/2.7D: U1.P$AD6 (D+)
D-/1.5D: D3.6 (I/O1_2)
D-/2.7D: U1.P$AD4 (D-)
DEC1: C5.1, U1.P$C1 (DEC1)
DEC3: C11.1, U1.P$D23 (DEC3)
DEC4_6: C10.1, C15.1, C16.1, L3.2, U1.P$B5 (DEC4), U1.P$E24 (DEC6)
DN: D3.1 (I/O1_1), J4.A7 (DN1), J4.B7 (DN2)
DP: D3.3 (I/O2_1), J4.A6 (DP1), J4.B6 (DP2)
EPD_3V3: C1-EP-DR.1, EPD_C5.2, J1.15, J1.16, L5.2, Q1.3 (D)
EPD_BUSY/1.5D: J1.9
EPD_BUSY/2.2D: U1.P$AD12 (P0.17)
EPD_CS/1.4C: J1.12
EPD_CS/2.2D: U1.P$AD10 (P0.15), U1.P$K2 (P0.05/AIN3)
EPD_DC/1.5D: J1.11
EPD_RST/1.5D: J1.10
EPD_RST/2.2D: U1.P$AC11 (P0.16)
GDR: J1.2, Q3.1 (G), R2_EP_DR.2
GND: C1.2, C1-EP-DR.2, C2.2, C3.2, C4.2, C5.2, C6.2, C7.2, C8.2, C9.2, C10.2, C11.2, C12.2, C13.2, C14.2, C15.2, C16.2, C17.1, C18.1, C19.2, C20.2, C21.2, C22.2, C23.2, C24.2, C25.2, C27.1, C29.2, C30.2, C31.2, C32.2, C33.2, C34.1, C37.2, C38.2, C39.2, C42.1, C43.2, D3.2 (GND), D4.1 (K), EPD_C1.1, EPD_C2.1, EPD_C5.1, EPD_C6.1, EPD_C7.1, EPD_C8.1, EPD_C9.1, EPD_C10.1, EPD_C11.1, EPD_C12.1, IC1.D2 (GND), IC2.B1 (IN/TRIG), IC2.B3 (GND), IC3.8 (GNDIO), IC3.9 (GND), IC9.B1 (VSEL), IC9.C1 (AGND), IC9.C2 (PGND_1), IC9.C3 (PGND_2), J1.8, J1.17, J1.MP1, J1.MP2, J2.3, J2.5, J4.A1_B12 (GND), J4.A12_B1 (GND), J4.SH1 (SHIELD), J4.SH2 (SHIELD), J4.SH3 (SHIELD), J4.SH4 (SHIELD), R1_USB.1, R2_EP_DR.1, R2_USB.2, R3.1, R9.1, R_TYPE_SEL.1, SJ1.1, SW1.1, SW_ENT.1, SW_UP.1, TP_BAT_GND.TP, TP_GND.TP, U1.P$74 (VSS_PAD), U1.P$75 (VSS_PAD), U1.P$76 (VSS_PAD), U1.P$77 (VSS_PAD), U1.P$78 (VSS_PAD), U1.P$79 (VSS_PAD), U1.P$80 (VSS_PAD), U1.P$81 (VSS_PAD), U1.P$82 (VSS_PAD), U1.P$83 (VSS_PAD), U1.P$84 (VSS_PAD), U1.P$85 (VSS_PAD), U1.P$86 (VSS_PAD), U1.P$87 (VSS_PAD), U1.P$88 (VSS_PAD), U1.P$89 (VSS_PAD), U1.P$90 (VSS_PAD), U1.P$B7 (VSS), U1.P$F23 (VSS_PA), U3.1 (CTG), U3.4 (GND), U3.6 (QSTRT), U3.9 (EP), X1.2, X1.4
HAPTIC_EN/1.4C: IC2.A1 (EN)
HAPTIC_EN/2.6A: U1.P$U1 (P0.12)
IMU_INT1: IC3.5 (INT1), U1.P$N1 (P0.08)
IMU_INT2: IC3.6 (INT2), U1.P$P2 (P1.08)
LX1: IC9.B2 (SW1_1), IC9.B3 (SW1_2), L7.1
LX2: IC9.D2 (SW2_1), IC9.D3 (SW2_2), L7.2
MOSI/1.5B: J1.14
MOSI/2.2D: U1.P$B13 (P0.03/AIN1)
unnamed: IC1.D1 (TS/MR), R9.2
unnamed: IC9.D1 (SCL), R4.2
unnamed: IC9.E1 (SDA), R2.2
unnamed: L2.2, L3.1
unnamed: L2.1, U1.P$B3 (DCC)
unnamed: IC3.1 (SDO), R3.2
unnamed: C13.1, U1.P$A18 (DEC2)
unnamed: C17.2, U1.P$D2 (P0.00/XL1), X2.1
unnamed: C18.2, U1.P$F2 (P0.01/XL2), X2.2
unnamed: C20.1, U1.P$AC5 (DEC3V3)
unnamed: C1.1, U1.P$B24 (XC1), X1.1
unnamed: C2.1, U1.P$A23 (XC2), X1.3
unnamed: C9.1, U1.P$N24 (DEC5)
unnamed: C3.1, L1.1, U1.P$H23 (ANT)
unnamed: ANT1.1 (FEED), C4.1, C22.1, L1.2
unnamed: C2-EP-DR.1, D2.1 (K), D4.2 (A)
unnamed: C2-EP-DR.2, D5.2 (A), L5.1, Q3.3 (D)
unnamed: R1_EP_DR.1, R_TYPE_SEL.2, SJ1.2
unnamed: EPD_C2.2, J1.4
unnamed: EPD_C1.2, J1.5
unnamed: EPD_C6.2, J1.18
unnamed: EPD_C7.2, J1.19
unnamed: EPD_C8.2, J1.20
unnamed: C32.1, IC2.A2 (REG)
unnamed: EPD_C10.2, J1.22
unnamed: J4.B5 (CC2), R2_USB.1
unnamed: EPD_C12.2, J1.24
unnamed: J4.A5 (CC1), R1_USB.2
OUT+: IC2.A3 (OUT+), TP_OP.TP
OUT-: IC2.C3 (OUT-), TP_ON.TP
P0.04: U1.P$J1 (P0.04/AIN2)
P0.09: U1.P$L24 (P0.09/NFC1)
P0.13/1.5D: C30.1, R5.1, SW_UP.2
P0.13/2.6C: U1.P$AD8 (P0.13)
P0.14/1.5D: C31.1, R8.1, SW_ENT.2
P0.14/2.7C: U1.P$AC9 (P0.14)
P0.19: U1.P$AC15 (P0.19)
P0.20: U1.P$AD16 (P0.20)
P0.21: U1.P$AC17 (P0.21)
P0.22: U1.P$AD18 (P0.22)
P0.23: U1.P$AC19 (P0.23)
P0.24: U1.P$AD20 (P0.24)
P0.25: U1.P$AC21 (P0.25)
P0.26: U1.P$G1 (P0.26)
P0.27: U1.P$H2 (P0.27)
P0.28: U1.P$B11 (P0.28/AIN4)
P0.29: U1.P$A10 (P0.29/AIN5)
P0.30: U1.P$B9 (P0.30/AIN6)
P0.31: U1.P$A8 (P0.31/AIN7)
P1.01/1.6C: Q1.1 (G), R_PWR_EPD.1
P1.01/2.4B: U1.P$Y23 (P1.01)
P1.02/1.6C: C29.1, R7.1, SW1.2
P1.02/2.8C: U1.P$W24 (P1.02)
P1.03: U1.P$V23 (P1.03)
P1.04: U1.P$U24 (P1.04)
P1.05: U1.P$T23 (P1.05)
P1.06: U1.P$R24 (P1.06)
P1.07: U1.P$P23 (P1.07)
P1.09: U1.P$R1 (P1.09)
P1.10: U1.P$A20 (P1.10)
P1.11: U1.P$B19 (P1.11)
P1.12: U1.P$B17 (P1.12)
P1.13: U1.P$A16 (P1.13)
P1.14: U1.P$B15 (P1.14)
P1.15: U1.P$A14 (P1.15)
PMIC_INT: IC1.A1 (!INT), U1.P$T2 (P0.11)
PREVGH: D5.1 (K), EPD_C9.2, J1.21
PREVGL: D2.2 (A), EPD_C11.2, J1.23
RESE: J1.3, Q3.2 (S), R1_EP_DR.2
RESET: J2.6, TP_RESET.TP, U1.P$AC13 (P0.18/RESET)
SCK/1.5B: J1.13
SCK/2.2D: U1.P$A12 (P0.02/AIN0)
SCL/1.4C: IC2.C1 (SCL), U3.7 (SCL)
SCL/2.4C: IC1.B1 (SCL), IC3.12 (SCX), R4.1, R17.2, TP_SCL.TP, U1.P$M2 (P0.07)
SDA/1.4C: IC2.B2 (SDA), U3.8 (SDA)
SDA/2.4C: IC1.C1 (SDA), IC3.2 (SDX), R2.1, R18.2, TP_SDA.TP, U1.P$L1 (P0.06)
SWDCLK: J2.4, TP_SWDCLK.TP, U1.P$AA24 (SWDCLK)
SWDIO: J2.2, TP_SWDIO.TP, U1.P$AC24 (SWDIO)
SWO: TP_SWO.TP, U1.P$AD22 (P1.00)
VBAT/1.2A: C27.2, TP_VBAT.TP, U3.2 (CELL), U3.3 (VDD)
VBAT/2.5C: C37.1, IC1.C2 (BAT)
VBUS/1.5D: C42.2, C43.1, D3.5 (VBUS), J4.A4_B9 (VBUS), J4.A9_B4 (VBUS)
VBUS/2.6D: C21.1, C38.1, IC1.A2 (IN), U1.P$AD2 (VBUS)
VREG: C23.1, C24.1, C39.1, IC1.B2 (SYS), IC9.A1 (EN), IC9.A2 (VIN_1), IC9.A3 (VIN_2), TP_VREG.TP

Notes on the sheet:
LiPo Charger
DC/DC
IMU
P0.00/XL1
P0.01/XL2
DEC4_6
N.C.
SWD
MCU, Power, IMU, SWD
drawn by: Andreea Plesu
InkTime v5
10.03.2026 16:50
1/2
E-Paper Drive Circuit
E-Paper Display Connector
Fuel Gauge
Haptic Driver
Buttons
USB C Connector & ESD Protection
E-Paper & Peripherals
draw by: Andreea Plesu
20.03.2026 21:30
2/2

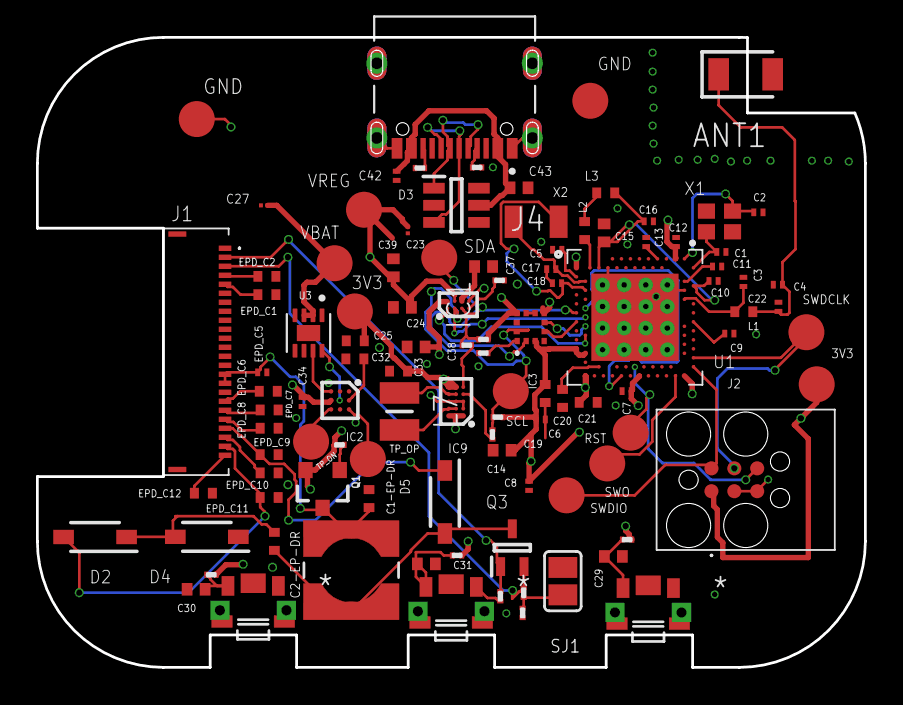
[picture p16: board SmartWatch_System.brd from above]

Board: 4 copper layers, 46.0 x 35.0 mm, 105 parts (0 on the bottom side), 66 nets.

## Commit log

2026-04-10 Add README.md with project documentation
    Added detailed project documentation for SmartWatch InkTime, including block diagram, bill of materials, hardware functionality, pin mapping, PCB design details, and repository structure.
2026-04-10 Revise PCB design section in README
    Updated PCB design details and added specifications.
2026-04-10 Insert block diagram and update system overview
    Add block diagram image and update description.
2026-04-10 Update PCB section in README with new layout
2026-04-10 Add schematic section to README
    Added schematic section with images to README.
2026-04-10 Update PCB and Schematic section headings in README
2026-04-10 Fix schematic image references in README
2026-04-20 Revise README with BOM and hardware details
    Updated the README.md to include a detailed Bill of Materials (BOM) section and improved the hardware description, including architecture and specifications.
2026-04-20 Update PCB design and schematic sections in README
2026-04-20 Fix formatting and image widths in README.md
    Corrected formatting issues in the PCB design section and adjusted image widths for better display.

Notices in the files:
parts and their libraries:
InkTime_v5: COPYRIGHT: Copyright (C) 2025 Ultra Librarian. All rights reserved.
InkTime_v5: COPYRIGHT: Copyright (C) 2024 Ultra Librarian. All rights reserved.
